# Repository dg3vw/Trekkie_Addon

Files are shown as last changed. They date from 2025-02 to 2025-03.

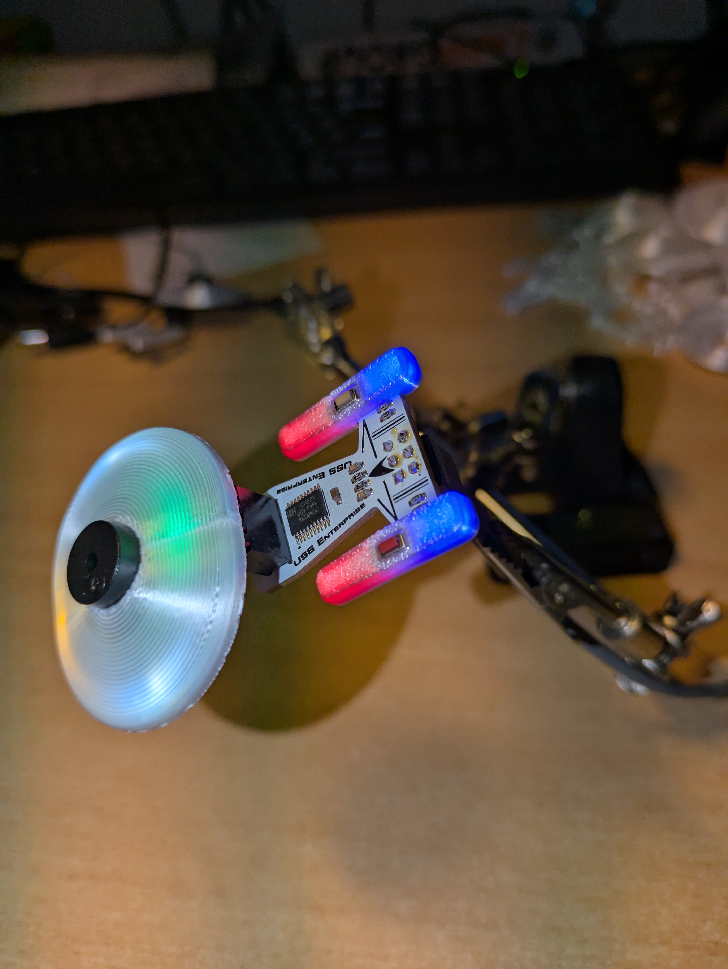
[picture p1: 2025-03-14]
pics/PXL_20250314_204137492.jpg

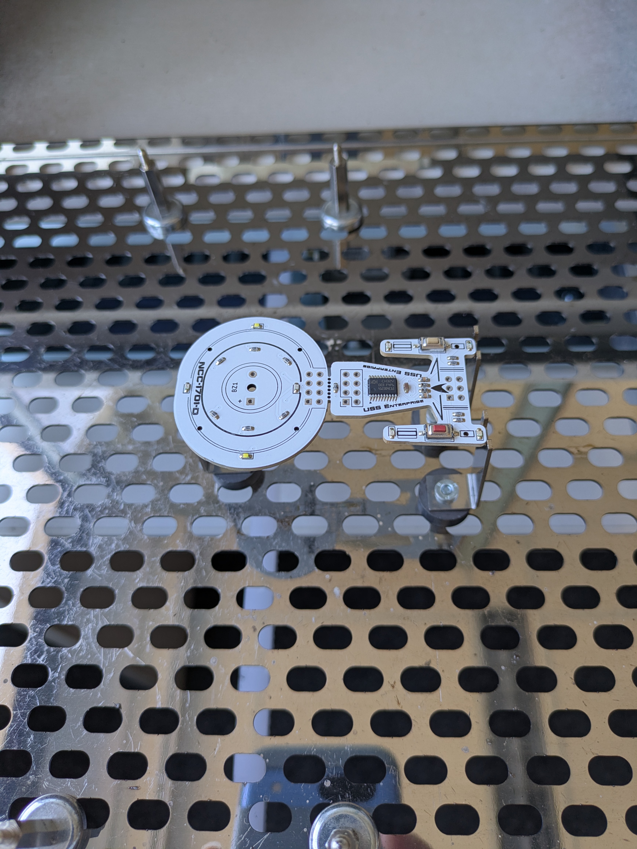
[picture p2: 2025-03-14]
pics/PXL_20250307_114811036.jpg

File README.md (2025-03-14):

# Trekkie_Addon - USS Enterprise SAO

my contribution to Hackaday Europe 2025 Badge SAO

## NCC-1701-D - USS Enterprise 
PXL_20250314_204249380 MP~2

### general 
* hardware compatible to 2024 Supercon 8 I2C prototyping petal SAO, using CH32v003 (see: https://github.com/Hack-a-Day/2024-Supercon-8-Add-On-Badge/tree/main/hardware/sao/i2c_proto_petal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)
* I added a few leds, two switches and a buzzer. Every LED is connected to a single gpio pin.
* you can change the light and sound as you wish, also with the PIpico on the badge

if u use my firmware, dont fire to much ;-)

### PINOUT: 
* PC0 - buzzer
* PC3 - front dish top led
* PC4 - engine nacelles left back
* PC5 - engine nacelles back
* PC6 - engine nacelles front
* PC7 - engine nacelles front
* PD0 - deflecor led
* PD1 - programming pin. connected to SAO connector pin 2
* PD2 - dish top left
* PD3 - dish top right
* PD4 - dish bottom left
* PD5 - dish bottom right
* PD6 - SWITCH 2 - fire the plasma cannon
* PD7 - SWITCH 1 - power up or reset (NRST), that can be changed to regular gpio using minichlink -D (from ch32fun)

## some impressions from the making:





PXL_20250314_204246564 MP

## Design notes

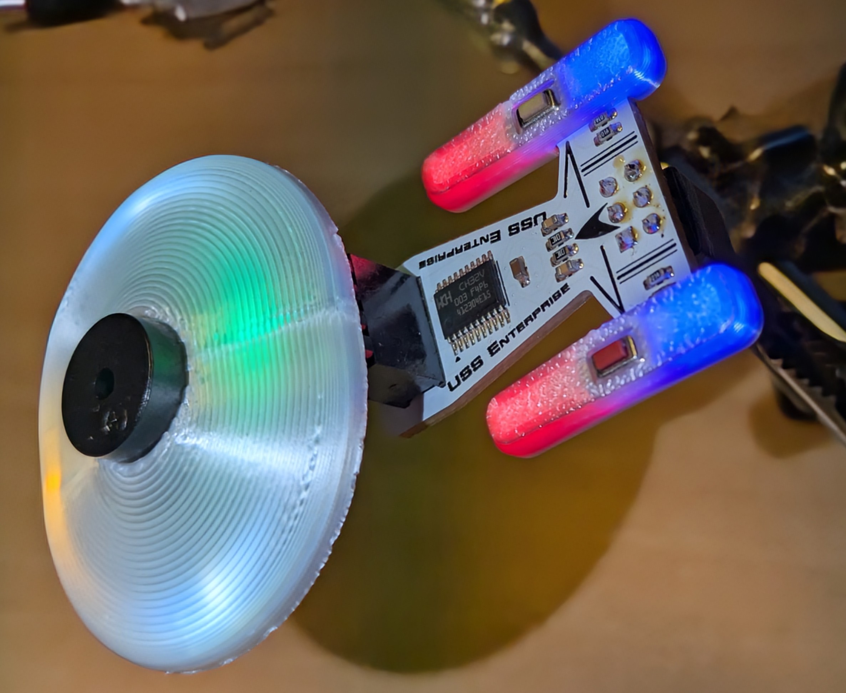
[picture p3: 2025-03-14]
pics/PXL_20250314_204137492~2.jpg

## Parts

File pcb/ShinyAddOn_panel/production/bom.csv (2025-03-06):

Designator | Footprint | Quantity | Value | LCSC Part #
BZ1_10, BZ1_9, BZ1_8, BZ1_7, BZ1_6, BZ1_5, BZ1_4, BZ1_3, BZ1_2, BZ1 | Buzzer_12x9.5RM7.6 | 10 | Buzzer
C1_10, C1_9, C1_8, C1_7, C1_6, C1_5, C1_4, C1_3, C1_2, C1, C2_10, C2_9, C2_8, C2_7, C2_6, C2_5, C2_4, C2_3, C2_2, C2 | 0603 | 20 | 1nF
C3_10, C3_9, C3_8, C3_7, C3_6, C3_5, C3_4, C3_3, C3_2, C3 | 0603 | 10 | 100nF
D1_10, D1_9, D1_8, D1_7, D1_6, D1_5, D1_4, D1_3, D1_2, D1 | 0603 | 10 | blue front powerled
D10_10, D10_9, D10_8, D10_7, D10_6, D10_5, D10_4, D10_3, D10_2, D10 | 0603 | 10 | LED dish bottom left
D11_10, D11_9, D11_8, D11_7, D11_6, D11_5, D11_4, D11_3, D11_2, D11 | 0603 | 10 | LED dish bottom right
D2_10, D2_9, D2_8, D2_7, D2_6, D2_5, D2_4, D2_3, D2_2, D2 | 0603 | 10 | lower front LED
D3_10, D3_9, D3_8, D3_7, D3_6, D3_5, D3_4, D3_3, D3_2, D3 | 0603 | 10 | LED blue right
D4_10, D4_9, D4_8, D4_7, D4_6, D4_5, D4_4, D4_3, D4_2, D4 | 0603 | 10 | LED blue left
D5_10, D5_9, D5_8, D5_7, D5_6, D5_5, D5_4, D5_3, D5_2, D5 | 0603 | 10 | LED blue front
D6_10, D6_9, D6_8, D6_7, D6_6, D6_5, D6_4, D6_3, D6_2, D6 | 0603 | 10 | LED red left
D7_10, D7_9, D7_8, D7_7, D7_6, D7_5, D7_4, D7_3, D7_2, D7 | 0603 | 10 | LED red right
D8_10, D8_9, D8_8, D8_7, D8_6, D8_5, D8_4, D8_3, D8_2, D8 | 0603 | 10 | LED dish top left
D9_10, D9_9, D9_8, D9_7, D9_6, D9_5, D9_4, D9_3, D9_2, D9 | 0603 | 10 | LED dish top right
J1_10, J1_9, J1_8, J1_7, J1_6, J1_5, J1_4, J1_3, J1_2, J1 | PinHeader_2x04_P2.54mm_Vertical | 10 | Conn_02x04_Odd_Even
J3_10, J3_9, J3_8, J3_7, J3_6, J3_5, J3_4, J3_3, J3_2, J3 | SolderJumper-2_P1.3mm_Open_RoundedPad1.0x1.5mm | 10 | GPIO
J4_10, J4_9, J4_8, J4_7, J4_6, J4_5, J4_4, J4_3, J4_2, J4 | PinSocket_2x04_P2.54mm_Vertical | 10 | saucer connetion
J5_10, J5_9, J5_8, J5_7, J5_6, J5_5, J5_4, J5_3, J5_2, J5 | PinHeader_2x03_P2.54mm_Vertical | 10 | SAO Connector
JP1_10, JP1_9, JP1_8, JP1_7, JP1_6, JP1_5, JP1_4, JP1_3, JP1_2, JP1 | SolderJumper-2_P1.3mm_Bridged_RoundedPad1.0x1.5mm | 10 | Jumper_2_Bridged
KIKIT_FID_B_1, KIKIT_FID_B_2, KIKIT_FID_B_3, KIKIT_FID_B_4, KIKIT_FID_T_1, KIKIT_FID_T_2, KIKIT_FID_T_3, KIKIT_FID_T_4 | Fiducial | 8 | Fiducial
KIKIT_MB_10_1, KIKIT_MB_10_2, KIKIT_MB_10_3, KIKIT_MB_10_4, KIKIT_MB_11_1, KIKIT_MB_11_2, KIKIT_MB_11_3, KIKIT_MB_11_4, KIKIT_MB_12_1, KIKIT_MB_12_2, KIKIT_MB_12_3, KIKIT_MB_12_4, KIKIT_MB_13_1, KIKIT_MB_13_2, KIKIT_MB_13_3, KIKIT_MB_13_4, KIKIT_MB_14_1, KIKIT_MB_14_2, KIKIT_MB_14_3, KIKIT_MB_14_4, KIKIT_MB_15_1, KIKIT_MB_15_2, KIKIT_MB_15_3, KIKIT_MB_15_4, KIKIT_MB_16_1, KIKIT_MB_16_2, KIKIT_MB_16_3, KIKIT_MB_16_4, KIKIT_MB_17_1, KIKIT_MB_17_2, KIKIT_MB_17_3, KIKIT_MB_17_4, KIKIT_MB_18_1, KIKIT_MB_18_2, KIKIT_MB_18_3, KIKIT_MB_18_4, KIKIT_MB_19_1, KIKIT_MB_19_2, KIKIT_MB_19_3, KIKIT_MB_19_4, KIKIT_MB_1_1, KIKIT_MB_1_2, KIKIT_MB_1_3, KIKIT_MB_1_4, KIKIT_MB_20_1, KIKIT_MB_20_2, KIKIT_MB_20_3, KIKIT_MB_20_4, KIKIT_MB_21_1, KIKIT_MB_21_2, KIKIT_MB_21_3, KIKIT_MB_21_4, KIKIT_MB_22_1, KIKIT_MB_22_2, KIKIT_MB_22_3, KIKIT_MB_22_4, KIKIT_MB_23_1, KIKIT_MB_23_2, KIKIT_MB_23_3, KIKIT_MB_23_4, KIKIT_MB_24_1, KIKIT_MB_24_2, KIKIT_MB_24_3, KIKIT_MB_24_4, KIKIT_MB_25_1, KIKIT_MB_25_2, KIKIT_MB_25_3, KIKIT_MB_25_4, KIKIT_MB_26_1, KIKIT_MB_26_2, KIKIT_MB_26_3, KIKIT_MB_26_4, KIKIT_MB_27_1, KIKIT_MB_27_2, KIKIT_MB_27_3, KIKIT_MB_27_4, KIKIT_MB_28_1, KIKIT_MB_28_2, KIKIT_MB_28_3, KIKIT_MB_28_4, KIKIT_MB_29_1, KIKIT_MB_29_2, KIKIT_MB_29_3, KIKIT_MB_29_4, KIKIT_MB_2_1, KIKIT_MB_2_2, KIKIT_MB_2_3, KIKIT_MB_2_4, KIKIT_MB_30_1, KIKIT_MB_30_2, KIKIT_MB_30_3, KIKIT_MB_30_4, KIKIT_MB_31_1, KIKIT_MB_31_2, KIKIT_MB_31_3, KIKIT_MB_31_4, KIKIT_MB_32_1, KIKIT_MB_32_2, KIKIT_MB_32_3, KIKIT_MB_32_4, KIKIT_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 | NPTH | 200 | NPTH
KIKIT_MB_46_8, KIKIT_MB_46_9, KIKIT_MB_47_1, KIKIT_MB_47_10, KIKIT_MB_47_11, KIKIT_MB_47_2, KIKIT_MB_47_3, KIKIT_MB_47_4, KIKIT_MB_47_5, KIKIT_MB_47_6, KIKIT_MB_47_7, KIKIT_MB_47_8, KIKIT_MB_47_9, KIKIT_MB_48_1, KIKIT_MB_48_10, KIKIT_MB_48_11, KIKIT_MB_48_2, KIKIT_MB_48_3, KIKIT_MB_48_4, KIKIT_MB_48_5, KIKIT_MB_48_6, KIKIT_MB_48_7, KIKIT_MB_48_8, KIKIT_MB_48_9, KIKIT_MB_4_1, KIKIT_MB_4_2, KIKIT_MB_4_3, KIKIT_MB_4_4, KIKIT_MB_5_1, KIKIT_MB_5_2, KIKIT_MB_5_3, KIKIT_MB_5_4, KIKIT_MB_6_1, KIKIT_MB_6_2, KIKIT_MB_6_3, KIKIT_MB_6_4, KIKIT_MB_7_1, KIKIT_MB_7_2, KIKIT_MB_7_3, KIKIT_MB_7_4, KIKIT_MB_8_1, KIKIT_MB_8_2, KIKIT_MB_8_3, KIKIT_MB_8_4, KIKIT_MB_9_1, KIKIT_MB_9_2, KIKIT_MB_9_3, KIKIT_MB_9_4, KIKIT_TO_1, KIKIT_TO_2, KIKIT_TO_3, KIKIT_TO_4 | NPTH | 52 | NPTH
R1_10, R1_9, R1_8, R1_7, R1_6, R1_5, R1_4, R1_3, R1_2, R1, R10_10, R10_9, R10_8, R10_7, R10_6, R10_5, R10_4, R10_3, R10_2, R10, R11_10, R11_9, R11_8, R11_7, R11_6, R11_5, R11_4, R11_3, R11_2, R11, R12_10, R12_9, R12_8, R12_7, R12_6, R12_5, R12_4, R12_3, R12_2, R12, R13_10, R13_9, R13_8, R13_7, R13_6, R13_5, R13_4, R13_3, R13_2, R13, R2_10, R2_9, R2_8, R2_7, R2_6, R2_5, R2_4, R2_3, R2_2, R2, R3_10, R3_9, R3_8, R3_7, R3_6, R3_5, R3_4, R3_3, R3_2, R3, R4_10, R4_9, R4_8, R4_7, R4_6, R4_5, R4_4, R4_3, R4_2, R4, R5_10, R5_9, R5_8, R5_7, R5_6, R5_5, R5_4, R5_3, R5_2, R5, R6_10, R6_9, R6_8, R6_7, R6_6, R6_5, R6_4, R6_3, R6_2, R6, R7_10, R7_9, R7_8, R7_7, R7_6, R7_5, R7_4, R7_3, R7_2, R7 | 0603 | 110 | 330
R8_10, R8_9, R8_8, R8_7, R8_6, R8_5, R8_4, R8_3, R8_2, R8, R9_10, R9_9, R9_8, R9_7, R9_6, R9_5, R9_4, R9_3, R9_2, R9 | 0603 | 20 | 10k
SW1_10, SW1_9, SW1_8, SW1_7, SW1_6, SW1_5, SW1_4, SW1_3, SW1_2, SW1, SW2_10, SW2_9, SW2_8, SW2_7, SW2_6, SW2_5, SW2_4, SW2_3, SW2_2, SW2 | SW_Tactile_SPST_NO_Straight_CK_PTS636Sx25SMTRLFS | 20 | SW_Push
U1_10, U1_9, U1_8, U1_7, U1_6, U1_5, U1_4, U1_3, U1_2, U1 | TSSOP-20_4.4x6.5mm_P0.65mm | 10 | CH32V003FxPx

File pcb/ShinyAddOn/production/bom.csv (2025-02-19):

Designator | Footprint | Quantity | Value | LCSC Part #
BZ1 | Buzzer_12x9.5RM7.6 | 1 | Buzzer
C1, C2 | 0603 | 2 | 1nF
C3 | 0603 | 1 | 100nF
D1 | 0603 | 1 | blue front powerled
D10 | 0603 | 1 | LED dish bottom left
D11 | 0603 | 1 | LED dish bottom right
D2 | 0603 | 1 | lower front LED
D3 | 0603 | 1 | LED blue right
D4 | 0603 | 1 | LED blue left
D5 | 0603 | 1 | LED blue front
D6 | 0603 | 1 | LED red left
D7 | 0603 | 1 | LED red right
D8 | 0603 | 1 | LED dish top left
D9 | 0603 | 1 | LED dish top right
J1 | PinHeader_2x04_P2.54mm_Vertical | 1 | Conn_02x04_Odd_Even
J3 | SolderJumper-2_P1.3mm_Open_RoundedPad1.0x1.5mm | 1 | GPIO
J4 | PinSocket_2x04_P2.54mm_Vertical | 1 | saucer connetion
J5 | PinHeader_2x03_P2.54mm_Vertical | 1 | SAO Connector
JP1 | SolderJumper-2_P1.3mm_Bridged_RoundedPad1.0x1.5mm | 1 | Jumper_2_Bridged
R1, R10, R11, R12, R13, R2, R3, R4, R5, R6, R7 | 0603 | 11 | 330
R8, R9 | 0603 | 2 | 10k
SW1, SW2 | SW_Tactile_SPST_NO_Straight_CK_PTS636Sx25SMTRLFS | 2 | SW_Push
U1 | TSSOP-20_4.4x6.5mm_P0.65mm | 1 | CH32V003FxPx

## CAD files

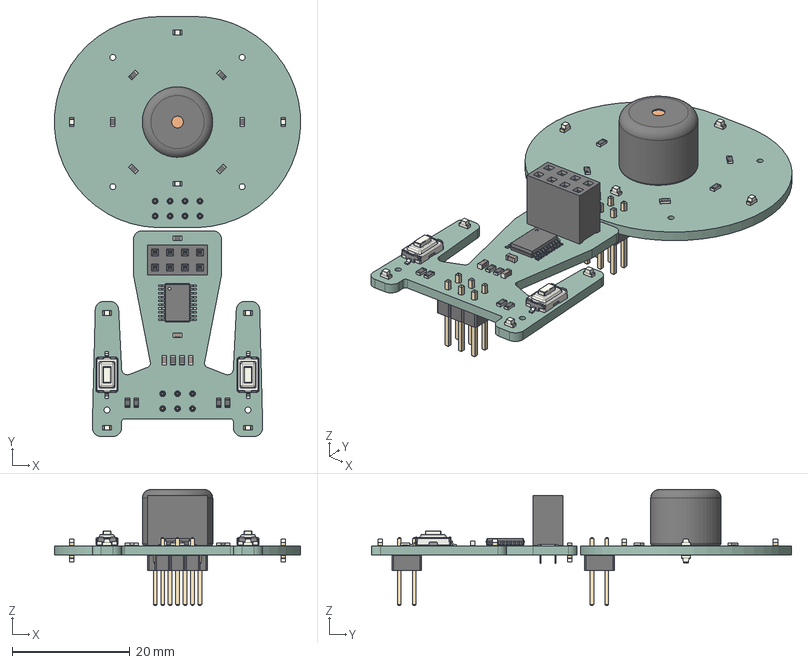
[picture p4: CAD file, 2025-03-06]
pcb/ShinyAddOn/ShinyAddOn.step
41.9 x 71.5 x 19.8 mm
SW_Tactile_SPST_NO_Straight_CK_PTS636Sx25SMTRLFS x 2
LED_0603_1608Metric x 11
C_0603_1608Metric x 3
R_0603_1608Metric x 13
TSSOP-20_4.4x6.5mm_P0.65mm
Buzzer_12x9.5RM7.6
PinSocket_2x04_P2.54mm_Vertical
PinHeader_2x04_P2.54mm_Vertical
PinHeader_2x03_P2.54mm_Vertical
ShinyAddOn_PCB_1
ShinyAddOn_PCB_2

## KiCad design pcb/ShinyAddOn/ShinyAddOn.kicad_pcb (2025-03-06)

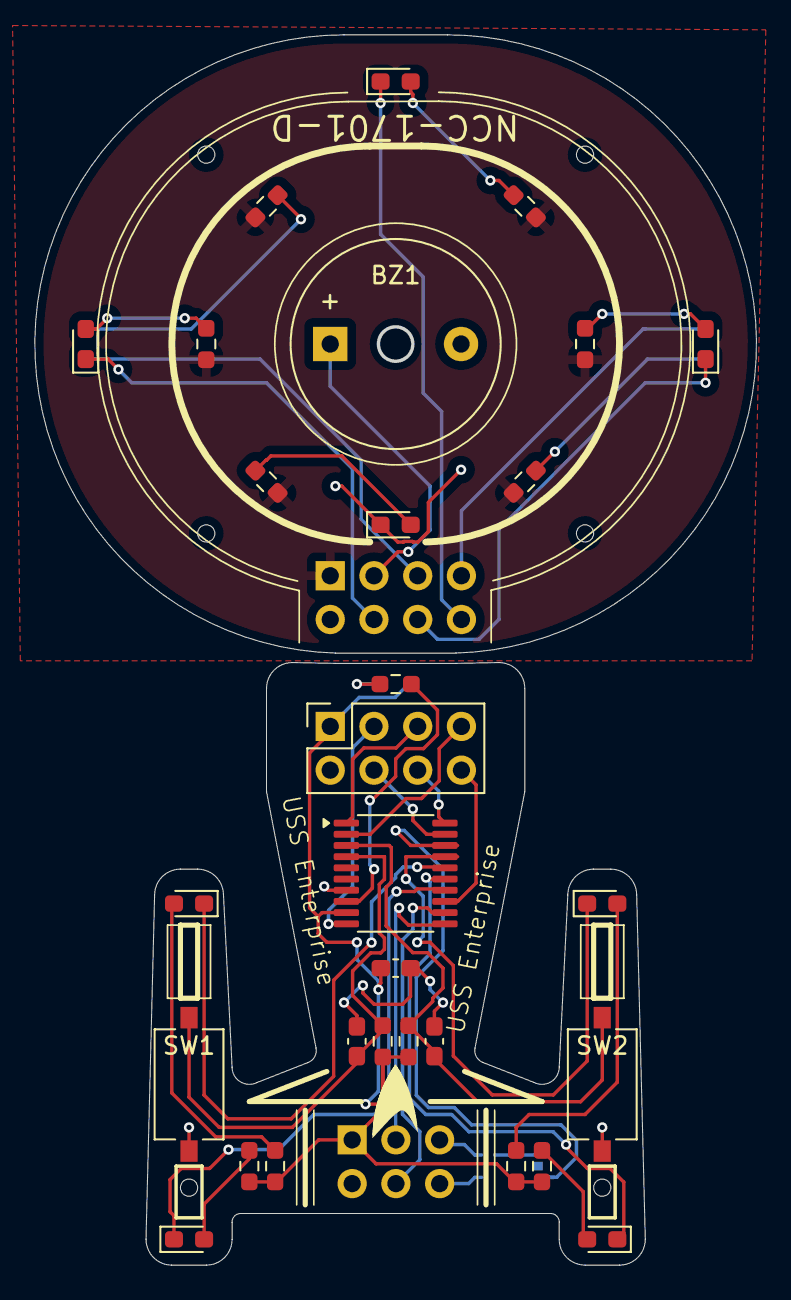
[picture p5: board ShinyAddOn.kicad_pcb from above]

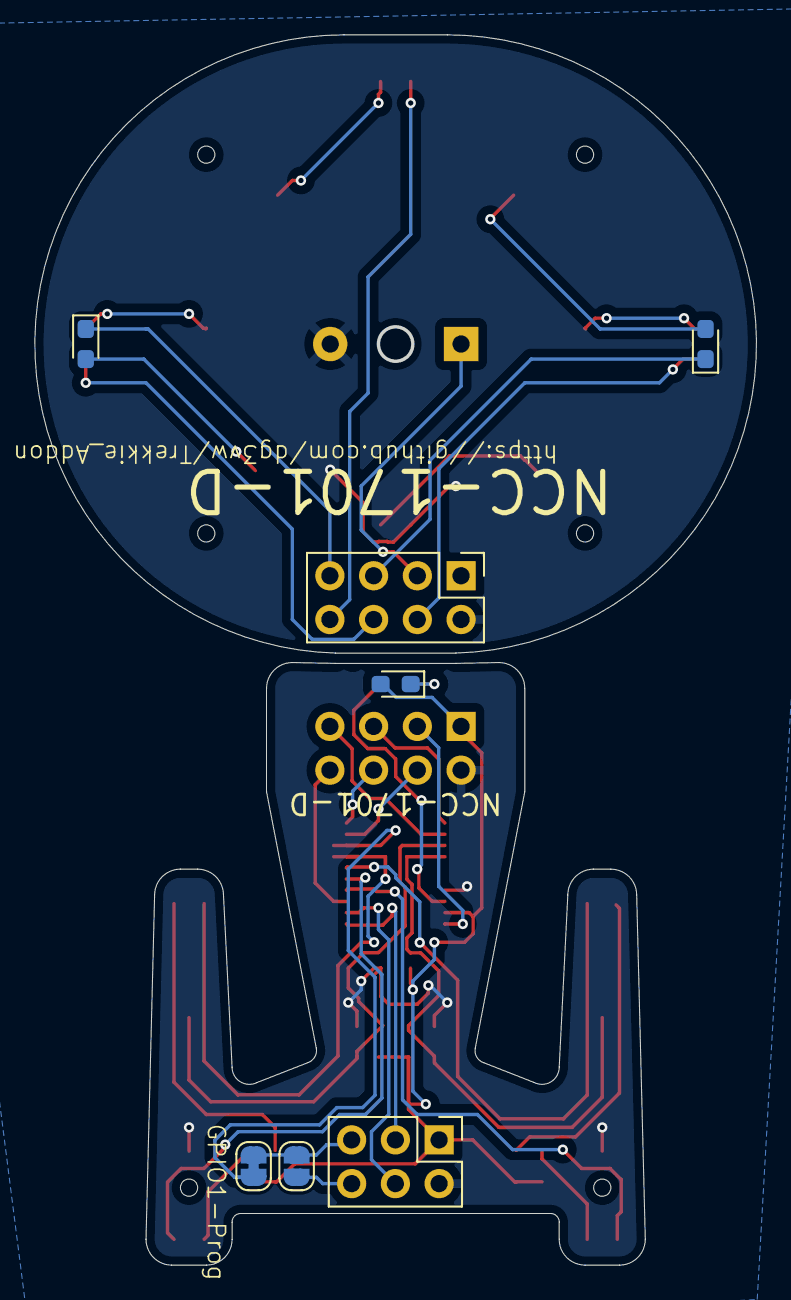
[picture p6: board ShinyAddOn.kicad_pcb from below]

Board: 2 copper layers, 41.9 x 71.5 mm, 36 parts (7 on the bottom side), 31 nets.

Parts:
BZ1: Buzzer; Buzzer_12x9.5RM7.6
C1, C2: 1nF; C_0603_1608Metric_Pad1.08x0.95mm_HandSolder
C3: 100nF; C_0603_1608Metric_Pad1.08x0.95mm_HandSolder
D1: blue front powerled; LED_0603_1608Metric_Pad1.05x0.95mm_HandSolder
D2: lower front LED; LED_0603_1608Metric_Pad1.05x0.95mm_HandSolder
D3: LED blue right; LED_0603_1608Metric_Pad1.05x0.95mm_HandSolder
D4: LED blue left; LED_0603_1608Metric_Pad1.05x0.95mm_HandSolder
D5: LED blue front; LED_0603_1608Metric_Pad1.05x0.95mm_HandSolder
D6: LED red left; LED_0603_1608Metric_Pad1.05x0.95mm_HandSolder
D7: LED red right; LED_0603_1608Metric_Pad1.05x0.95mm_HandSolder
D8: LED dish top left; LED_0603_1608Metric_Pad1.05x0.95mm_HandSolder
D9: LED dish top right; LED_0603_1608Metric_Pad1.05x0.95mm_HandSolder
D10: LED dish bottom left; LED_0603_1608Metric_Pad1.05x0.95mm_HandSolder
D11: LED dish bottom right; LED_0603_1608Metric_Pad1.05x0.95mm_HandSolder
J1: Conn_02x04_Odd_Even; PinHeader_2x04_P2.54mm_Vertical
J3: GPIO; SolderJumper-2_P1.3mm_Open_RoundedPad1.0x1.5mm
J4: saucer connetion; PinSocket_2x04_P2.54mm_Vertical
J5: SAO Connector; PinHeader_2x03_P2.54mm_Vertical
JP1: Jumper_2_Bridged; SolderJumper-2_P1.3mm_Bridged_RoundedPad1.0x1.5mm
R1, R2, R3, R4, R5, R6, R7, R10, R11, R12, R13: 330; R_0603_1608Metric_Pad0.98x0.95mm_HandSolder
R8, R9: 10k; R_0603_1608Metric_Pad0.98x0.95mm_HandSolder
SW1, SW2: SW_Push; SW_Tactile_SPST_NO_Straight_CK_PTS636Sx25SMTRLFS
U1: CH32V003FxPx; TSSOP-20_4.4x6.5mm_P0.65mm

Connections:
/GPIO1: J3.2, J5.5, JP1.1 (A)
/GPIO2: J3.1, J5.6
/LED dish bottom l: D10.1 (K), J1.5, J4.5, U1.1 (PD4)
/LED dish bottom r: D11.1 (K), J1.7, J4.7, U1.2 (PD5)
/LED dish top left: D8.1 (K), J1.4, J4.4, U1.19 (PD2)
/LED dish top right: D9.1 (K), J1.6, J4.6, U1.20 (PD3)
/SCL: J5.4, U1.12 (SCL)
/SDA: J5.3, U1.11 (SDA)
/blue gondeln left: D4.1 (K), U1.14 (PC4)
/blue gondeln right: D3.1 (K), U1.15 (PC5)
/blue_front: D5.1 (K), J1.8, J4.8, U1.13 (PC3)
/buzzer: BZ1.1 (+), J1.3, J4.3, U1.10 (PC0)
/red_gondeln_left: D6.1 (K), U1.16 (PC6)
/red_gondeln_right: D7.1 (K), U1.17 (PC7)
/sw1: C1.1, R9.2, SW1.1, U1.4 (PD7)
/sw2: C2.1, R8.2, SW2.1, U1.3 (PD6)
GND: BZ1.2 (-), C1.2, C2.2, C3.2, D1.1 (K), J1.2, J4.2, J5.2, SW1.2, SW2.2, U1.7 (VSS)
unnamed: D1.2 (A), R1.2
unnamed: D2.1 (K), R2.1
unnamed: D3.2 (A), R3.2
unnamed: D4.2 (A), R4.2
unnamed: D5.2 (A), R5.2
unnamed: D6.2 (A), R6.2
unnamed: D7.2 (A), R7.2
unnamed: D8.2 (A), R10.2
unnamed: D9.2 (A), R11.2
unnamed: D10.2 (A), R12.2
unnamed: D11.2 (A), R13.2
unnamed: JP1.2 (B), U1.18 (SWIO)
unnamed: R2.2, U1.8 (PD0)
VCC: C3.1, D2.2 (A), J1.1, J4.1, J5.1, R1.1, R3.1, R4.1, R5.1, R6.1, R7.1, R8.1, R9.1, R10.1, R11.1, R12.1, R13.1, U1.9 (VDD)

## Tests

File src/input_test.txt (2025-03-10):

#include <Arduino.h>
#define LED_DISH_BOTTOM_LEFT PD4
#define LED_DISH_BOTTOM_RIGHT PD5

// Function to configure PD7 as an input pin
void configurePD7AsInput() {
  // Enable the clock for GPIO port D
  RCC_APB2PeriphClockCmd(RCC_APB2Periph_GPIOD, ENABLE);

  // Configure PD7 as an input with pull-up resistor
  GPIO_InitTypeDef GPIO_InitStructure;
  GPIO_InitStructure.GPIO_Pin = GPIO_Pin_7;
  GPIO_InitStructure.GPIO_Mode = GPIO_Mode_IPU; // Use GPIO_Mode_IPU for internal pull-up
  GPIO_Init(GPIOD, &GPIO_InitStructure);
}

void setup() {
  // Configure PD7 as input
  configurePD7AsInput();
  pinMode(LED_DISH_BOTTOM_LEFT, OUTPUT);
  pinMode(LED_DISH_BOTTOM_RIGHT, OUTPUT);

  digitalWrite(LED_DISH_BOTTOM_RIGHT, LOW); 

}

void loop() {
  // Read the state of PD7
  int pd7State = digitalRead(PD7);

  // Print the state to the serial monitor
  if (pd7State == HIGH) {
    digitalWrite(LED_DISH_BOTTOM_LEFT, HIGH);
  } else {
    digitalWrite(LED_DISH_BOTTOM_LEFT, LOW);
  }

  // Delay for 1 second
  delay(1000);
}

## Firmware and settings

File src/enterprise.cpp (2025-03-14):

#include <NonBlockingRtttl.h>
#include <Arduino.h>

// Define LED pins
#define LED_FRONT PC3
#define BUZZER PC0
#define LED_BLUE_MOTOR_LEFT PC4
#define LED_BLUE_MOTOR_RIGHT PC5
#define LED_RED_MOTOR_LEFT PC6
#define LED_RED_MOTOR_RIGHT PC7
#define LED_DISH_TOP_LEFT PD2
#define LED_DISH_TOP_RIGHT PD3
#define LED_DISH_BOTTOM_LEFT PD4
#define LED_DISH_BOTTOM_RIGHT PD5
#define LED_DEFLECTOR PD0
#define SWITCH_1 PD6
#define SWITCH_2 PD7 // <- work only if Pin D7 is reprogrammed to be an input (not NRST)

// Structure to hold LED timing parameters
struct LedTiming {
    unsigned long previousMillis;
    int ledState;
    const long (*intervalData)[3]; // Pointer to an array of arrays [on, off, repeat]
    const int numIntervals;        // Number of intervals in the array
    const int ledPin;
    int timingIndex;         // Index to switch between the timing sets
    int currentRepeat; // Counter for the current repeat of the interval
};

// Define interval arrays for each LED (example)
// Top Dish LEDs
const long topDishLeftData[][3] = {
    {2000, 15, 1},   // 100ms ON, 900ms OFF, repeat 3 times
    
};

const long topDishRightData[][3] = {
    {2100, 15, 1},   // 100ms ON, 900ms OFF, repeat 3 times
};

// Bottom Dish LEDs
const long bottomDishLeftData[][3] = {
    {50, 50, 4},    // 500ms ON, 100ms OFF, repeat 1 time
    {50, 200, 1},   // 200ms ON, 500ms OFF, repeat 2 time
    {2000, 350, 1},   // 200ms ON, 500ms OFF, repeat 2 time
};

const long bottomDishRightData[][3] = {
    {50, 50, 4},    // 500ms ON, 100ms OFF, repeat 1 time
    {50, 200, 1},   // 200ms ON, 500ms OFF, repeat 2 time
    {2000, 350, 1},   // 200ms ON, 500ms OFF, repeat 2 time
};

// Front LED
const long frontLedData[][3] = {
    {2500, 500, 1},   // 5000ms ON, 60ms OFF, repeat 1 time
};

// Blue Motor LEDs
const long blueMotorLeftData[][3] = {
    {100, 50, 1},
    {50, 200, 1},   
    {6000, 2000, 1},   
};

const long blueMotorRightData[][3] = {
    {100, 50, 1},
    {50, 200, 1},   
    {6000, 2000, 1},
};

// Red Motor LEDs
const long redMotorLeftData[][3] = {
    {5000, 500, 1},   // 5000ms ON, 60ms OFF, repeat 1 time
};

const long redMotorRightData[][3] = {
    {5000, 500, 1},   // 5000ms ON, 60ms OFF, repeat 1 time
};

// Deflector LED
const long deflectorLedData[][3] = {
    {3000, 700, 1},   // 5000ms ON, 60ms OFF, repeat 1 time
};

// Define LED timing parameters and instances
LedTiming topDishLeds[] = {
    {0, LOW, topDishLeftData, sizeof(topDishLeftData) / sizeof(topDishLeftData[0]), LED_DISH_TOP_LEFT, 0, 0},
    {0, LOW, topDishRightData, sizeof(topDishRightData) / sizeof(topDishRightData[0]), LED_DISH_TOP_RIGHT, 0, 0}};

LedTiming bottomDishLeds[] = {
    {0, LOW, bottomDishLeftData, sizeof(bottomDishLeftData) / sizeof(bottomDishLeftData[0]), LED_DISH_BOTTOM_LEFT, 0, 0},
    {0, LOW, bottomDishRightData, sizeof(bottomDishRightData) / sizeof(bottomDishRightData[0]), LED_DISH_BOTTOM_RIGHT, 0, 0}};

LedTiming frontLed = {0, LOW, frontLedData, sizeof(frontLedData) / sizeof(frontLedData[0]), LED_FRONT, 0, 0};

LedTiming blueMotorLeds[] = {
    {0, LOW, blueMotorLeftData, sizeof(blueMotorLeftData) / sizeof(blueMotorLeftData[0]), LED_BLUE_MOTOR_LEFT, 0, 0},
    {0, LOW, blueMotorRightData, sizeof(blueMotorRightData) / sizeof(blueMotorRightData[0]), LED_BLUE_MOTOR_RIGHT, 0, 0}};

LedTiming redMotorLeds[] = {
    {0, LOW, redMotorLeftData, sizeof(redMotorLeftData) / sizeof(redMotorLeftData[0]), LED_RED_MOTOR_LEFT, 0, 0},
    {0, LOW, redMotorRightData, sizeof(redMotorRightData) / sizeof(redMotorRightData[0]), LED_RED_MOTOR_RIGHT, 0, 0}};

LedTiming deflectorLed = {0, LOW, deflectorLedData, sizeof(deflectorLedData) / sizeof(deflectorLedData[0]), LED_DEFLECTOR, 0, 0};

static bool switch1Pressed = false; // Flag to track switch 1 press state
static bool switch2Pressed = false; // Flag to track switch 2 press state
unsigned long currentMillis = millis();

int leds[] = {
    LED_FRONT, LED_BLUE_MOTOR_LEFT, LED_BLUE_MOTOR_RIGHT,
    LED_RED_MOTOR_LEFT, LED_RED_MOTOR_RIGHT, LED_DISH_TOP_LEFT,
    LED_DISH_TOP_RIGHT, LED_DISH_BOTTOM_LEFT, LED_DISH_BOTTOM_RIGHT,
    LED_DEFLECTOR};

const char *startrek = "StarTrekTNG:d=32,o=6,b=63:8f#.5,b.5,d#.,8c#.,a.5,g#.,4f#.,a.5,e.,f#.,g#.,e.,8d#,8c#,8b.5,d#.,b.5,2c#";
const char *rickroll = "RickRoll:d=4,o=5,b=200:8g,8a,8c6,8a,e6,8p,e6,8p,d6.,p,8p,8g,8a,8c6,8a,d6,8p,d6,8p,c6,8b,a.,8g,8a,8c6,8a,2c6,d6,b,a,g.,8p,g,2d6,2c6.,p,8g,8a,8c6,8a,e6,8p,e6,8p,d6.,p,8p,8g,8a,8c6,8a,2g6,b,c6.,8b,a,8g,8a,8c6,8a,2c6,d6,b,a,g.,8p,g,2d6,2c6.";


// Zapping sound parameters (for SWITCH_1)
const int zapFrequencies[] = {400, 600, 800, 1000, 800, 600, 400, 300, 200}; // Frequencies for the zap sound
const long zapDurations[] = {20, 20, 20, 20, 20, 20, 20, 30, 50};   // Durations for each frequency (milliseconds)
const int numZapTones = sizeof(zapFrequencies) / sizeof(zapFrequencies[0]);
unsigned long zapStartTime = 0; // Stores the start time of the zap sound
int zapToneIndex = 0;          // Index of the current tone
bool isZapping = false;        // Flag to indicate if the zapping sound is playing

// New sound parameters (for SWITCH_2)
const int beepFrequencies[] = {800, 1200, 1600, 2000}; // Frequencies for the beep sound
const long beepDurations[] = {50, 50, 50, 100};        // Durations for each frequency (milliseconds)
const int numBeepTones = sizeof(beepFrequencies) / sizeof(beepFrequencies[0]);
unsigned long beepStartTime = 0; // Stores the start time of the beep sound
int beepToneIndex = 0;          // Index of the current tone
bool isBeeping = false;        // Flag to indicate if the beep sound is playing

// New variables for rickroll functionality
int switch1PressCount = 0; // Counter for switch 1 presses
bool isRickrolling = false;  // Flag to indicate if Rickroll is playing
unsigned long rickrollBlinkMillis = 0;
int rickrollBlinkState = LOW;


// Function to play Rickroll
void playRickroll() {
    if (!isRickrolling) {
        isRickrolling = true;
        rtttl::begin(BUZZER, rickroll);
    }
    if (rtttl::done()) {
        isRickrolling = false;
        //reset leds
        for (int i = 0; i < sizeof(leds) / sizeof(leds[0]); i++) {
            digitalWrite(leds[i], HIGH); 
        }
    } else {
        rtttl::play();
    }
}

void setup() {
    pinMode(LED_FRONT, OUTPUT);
    pinMode(BUZZER, OUTPUT);
    pinMode(LED_BLUE_MOTOR_LEFT, OUTPUT);
    pinMode(LED_BLUE_MOTOR_RIGHT, OUTPUT);
    pinMode(LED_RED_MOTOR_LEFT, OUTPUT);
    pinMode(LED_RED_MOTOR_RIGHT, OUTPUT);
    pinMode(LED_DISH_TOP_LEFT, OUTPUT);
    pinMode(LED_DISH_TOP_RIGHT, OUTPUT);
    pinMode(LED_DISH_BOTTOM_LEFT, OUTPUT);
    pinMode(LED_DISH_BOTTOM_RIGHT, OUTPUT);
    pinMode(LED_DEFLECTOR, OUTPUT);
    pinMode(SWITCH_1, INPUT_PULLUP); // Use internal pull-up resistor
    pinMode(SWITCH_2, INPUT_PULLUP); // Use internal pull-up resistor

    for (int i = 0; i < sizeof(leds) / sizeof(leds[0]); i++) {
        digitalWrite(leds[i], HIGH); // Start all LEDs as off
    }

    rtttl::begin(BUZZER, startrek);
    while (!rtttl::done()) {
        rtttl::play();
    }
}

void handleLedBlinking(LedTiming &led) {
    unsigned long currentMillis = millis();
    long intervalOn = led.intervalData[led.timingIndex][0];
    long intervalOff = led.intervalData[led.timingIndex][1];
    int intervalRepeat = led.intervalData[led.timingIndex][2];

    if (led.ledState == LOW && currentMillis - led.previousMillis >= intervalOn) {
        led.previousMillis = currentMillis;
        led.ledState = HIGH;
        digitalWrite(led.ledPin, led.ledState);
    } else if (led.ledState == HIGH && currentMillis - led.previousMillis >= intervalOff) {
        led.previousMillis = currentMillis;
        led.ledState = LOW;
        digitalWrite(led.ledPin, led.ledState);
        led.currentRepeat++;

        if (led.currentRepeat >= intervalRepeat) {
            led.timingIndex = (led.timingIndex + 1) % led.numIntervals;
            led.currentRepeat = 0; // Reset the repeat counter
        }
    }
}


void handleLedGroupBlinking(LedTiming leds[], int count) {
    for (int i = 0; i < count; i++) {
        handleLedBlinking(leds[i]);
    }
}

// Function to play the zapping sound
void playZapSound() {
    if (isZapping) {
        unsigned long currentMillis = millis();
        if (currentMillis - zapStartTime >= zapDurations[zapToneIndex]) {
            zapToneIndex++;
            zapStartTime = currentMillis;
            if (zapToneIndex >= numZapTones) {
                isZapping = false;
                noTone(BUZZER);
            } else {
                tone(BUZZER, zapFrequencies[zapToneIndex]);
            }
        }
    }
}
// Function to play the new beep sound (for SWITCH_2)
void playBeepSound() {
    if (isBeeping) {
        unsigned long currentMillis = millis();
        if (currentMillis - beepStartTime >= beepDurations[beepToneIndex]) {
            beepToneIndex++;
            beepStartTime = currentMillis;
            if (beepToneIndex >= numBeepTones) {
                isBeeping = false;
                noTone(BUZZER);
            } else {
                tone(BUZZER, beepFrequencies[beepToneIndex]);
            }
        }
    }
}

void rickrollBlink() {
    unsigned long currentMillis = millis();
    if (currentMillis - rickrollBlinkMillis >= 50) {
        rickrollBlinkMillis = currentMillis;
        rickrollBlinkState = !rickrollBlinkState; // Toggle state
        if (rickrollBlinkState == HIGH) {
            int randomIndex = random(sizeof(leds) / sizeof(leds[0]));
            digitalWrite(leds[randomIndex], LOW);
        } else {
            for (int i = 0; i < sizeof(leds) / sizeof(leds[0]); i++) {
                digitalWrite(leds[i], HIGH);
            }
        }
    }
}

void loop() {
    unsigned long currentMillis = millis(); // Moved inside the loop!

    if (!isRickrolling) {
        // Handle top dish LEDs blinking
        handleLedGroupBlinking(topDishLeds, sizeof(topDishLeds) / sizeof(topDishLeds[0]));

        // Handle bottom dish LEDs blinking
        handleLedGroupBlinking(bottomDishLeds, sizeof(bottomDishLeds) / sizeof(bottomDishLeds[0]));

        // Handle Front LED blinking
        handleLedBlinking(frontLed);

        // Handle blue motor LEDs blinking
        handleLedGroupBlinking(blueMotorLeds, sizeof(blueMotorLeds) / sizeof(blueMotorLeds[0]));

        // Handle red motor LEDs blinking
        handleLedGroupBlinking(redMotorLeds, sizeof(redMotorLeds) / sizeof(redMotorLeds[0]));
    }

    // Handle deflector LED blinking when switch 1 is pressed and play sound
    if (digitalRead(SWITCH_1) == LOW) { // Switch is active LOW
        if (!switch1Pressed) {
            switch1PressCount++;
            switch1Pressed = true;
            if (!isZapping) {
                isZapping = true;
                zapToneIndex = 0;
                zapStartTime = currentMillis;
                tone(BUZZER, zapFrequencies[zapToneIndex]);
            }
        }
    } else {
        switch1Pressed = false;
        if (switch1PressCount >= 10 && !isRickrolling) {
            switch1PressCount = 0;
            playRickroll();
        }
    }

    if(isRickrolling){
        rickrollBlink();
        playRickroll();
    }

    // Handle new beep sound when switch 2 is pressed <- work only if Pin D7 is reprogrammed to be an input (not NRST)
    if (digitalRead(SWITCH_2) == LOW) { // Switch is active LOW
        switch2Pressed = true;
        if (!isBeeping) {
            isBeeping = true;
            beepToneIndex = 0;
            beepStartTime = currentMillis;
            tone(BUZZER, beepFrequencies[beepToneIndex]);
        }
    } else {
        switch2Pressed = false;
    }

    if (switch1Pressed && !isRickrolling) {
                handleLedBlinking(deflectorLed);
             } else if(!isRickrolling) {
                 digitalWrite(LED_DEFLECTOR, HIGH); // Keep deflector off when switch is not pressed
             }
             
             if (!isRickrolling) {
                 playZapSound(); // Play the zapping sound if it's active
             } 
             playBeepSound(); // Play the beep sound if it's active
        
        }

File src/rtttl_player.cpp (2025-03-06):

#include <NonBlockingRtttl.h>

//project's contants
#define BUZZER_PIN PC0
#define BLUE_LED_PIN PD0
const char * tetris = "tetris:d=4,o=5,b=160:e6,8b,8c6,8d6,16e6,16d6,8c6,8b,a,8a,8c6,e6,8d6,8c6,b,8b,8c6,d6,e6,c6,a,2a,8p,d6,8f6,a6,8g6,8f6,e6,8e6,8c6,e6,8d6,8c6,b,8b,8c6,d6,e6,c6,a,a";
const char * arkanoid = "Arkanoid:d=4,o=5,b=140:8g6,16p,16g.6,2a#6,32p,8a6,8g6,8f6,8a6,2g6";
const char * startrek = "Star Trek:o=5,d=16,b=63,b=63:8f.,a#,4d#6.,8d6,a#.,g.,c6.,4f6";
const char * startrekng = "StarTrekTNG:d=32,o=6,b=63:8f#.5,b.5,d#.,8c#.,a.5,g#.,4f#.,a.5,e.,f#.,g#.,e.,8d#,8c#,8b.5,d#.,b.5,2c#";
const char * mario = "mario:d=4,o=5,b=100:16e6,16e6,32p,8e6,16c6,8e6,8g6,8p,8g,8p,8c6,16p,8g,16p,8e,16p,8a,8b,16a#,8a,16g.,16e6,16g6,8a6,16f6,8g6,8e6,16c6,16d6,8b,16p,8c6,16p,8g,16p,8e,16p,8a,8b,16a#,8a,16g.,16e6,16g6,8a6,16f6,8g6,8e6,16c6,16d6,8b,8p,16g6,16f#6,16f6,16d#6,16p,16e6,16p,16g#,16a,16c6,16p,16a,16c6,16d6,8p,16g6,16f#6,16f6,16d#6,16p,16e6,16p,16c7,16p,16c7,16c7,p,16g6,16f#6,16f6,16d#6,16p,16e6,16p,16g#,16a,16c6,16p,16a,16c6,16d6,8p,16d#6,8p,16d6,8p,16c6";
const char * giveyouup = "GiveYouUp:d=4,o=5,b=200:8g,8a,8c6,8a,e6,8p,e6,8p,d.6,p,8p,8g,8a,8c6,8a,d6,8p,d6,8p,c6,8b,a.,8g,8a,8c6,8a,2c6,d6,b,a,g.,8p,g,2d6,2c.6,p,8g,8a,8c6,8a,e6,8p,e6,8p,d.6,p,8p,8g,8a,8c6,8a,2g6,b,c.6,8b,a,8g,8a,8c6,8a,2c6,d6,b,a,g.,8p,g,2d6,2c.6";
const char * pirates = "Piratesof:d=4,o=6,b=100:8a.5,8c.,8d.,8c,16a_5,8a5,16a5,8g5,16g5,f5,16p,16a5,16a.5,32p,16a5,16a5,16a5,16a5,16a5,16a5,16a5,16a5,16a5,16a5,16d.,32p,16a5,16f5,16f5,16g5,16a.5,p,16a5,16a_5,16a_5,16a_5,16g5,16g5,16g5,16a5,16a5,16a5,16f5,16f5,16f5,16g5,16g5,16g5,16g5,16a5";
const char * thegood = "Thegood,:d=4,o=6,b=63:32c,32f,32c,32f,c,8g_5,8a_5,f5,8p,32c,32f,32c,32f,c,8g_5,8a_5,d_";
const char * startrek1 = "we-rock:d=4,o=6,b=225:2b.4,4e.5,1a5,4g#.5,4e.5,4c#.5,4f#.5,2b.5,4b.5,2d#.6,";
const char * startrek2 = "StarTrek:d=4,o=5,b=80:8g,16c6,f6,16e6,16c6,16a,16d6,8g6,8p,8g,16c6,f6,16e6,16c6,16a,16d6,8g6";
const char * startrek3 = "Star Trek: d=4,o=5,b=63:8f.,16a#,d#.6,8d6,16a#.,16g.,16c.6,f6";
const char * startrek4 = "TheNextG:d=4,o=5,b=100:8f#6,16a#6,16a#6,16d#7,8c#7,16p,16g#6,16g#7,16g#7,8f#7,8p,16g#6,8f#7,16p,8d#7,16p,8d#7,16p,16d#7,16a#6,16d#7,8c#7";   
const char * startrek5 = "Communic:d=4,o=5,b=100:16g#7,8a#7,16a#7,16a#7,8f#7";

byte songIndex = 0; //which song to play when the previous one finishes

void setup() {
  pinMode(BUZZER_PIN, OUTPUT);
  pinMode(BLUE_LED_PIN, OUTPUT);

  Serial.begin(115200);
  Serial.println();
  
}

void loop() {
  if ( !rtttl::isPlaying() )
  {
    if (songIndex == 0)
    {
      rtttl::begin(BUZZER_PIN, startrek5);
      songIndex++; //ready for next song
      delay(5000);

      //play for 5 sec then stop.
      //note: this is a blocking code section
      //used to demonstrate the use of stop
      /*unsigned long start = millis();
      while( millis() - start < 5000 ) 
      {
        rtttl::play();
      }
      rtttl::stop();
      */
    }
    else if (songIndex == 1)
    {
      rtttl::begin(BUZZER_PIN, startrek2 );
      songIndex++; //ready for next song
      delay(5000); //play for 5 sec then stop.
    }
    else if (songIndex == 2)
    {
      rtttl::begin(BUZZER_PIN,startrekng);
      songIndex++; //ready for next song
    }
  }
  else
  {
    rtttl::play();
  }
}

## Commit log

2025-02-02 initial commit, pcb und platformio project data added
    [ShinyAddOn.kicad_pcb, ShinyAddOn.kicad_sch]
2025-02-16 worked on the pcb
    [ShinyAddOn.kicad_pcb, ShinyAddOn.kicad_sch]
2025-02-19 pcb updated
    [ShinyAddOn.kicad_pcb, ShinyAddOn.kicad_sch, ShinyAddOn_panel.kicad_pcb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]
2025-03-06 panel tests
    [ShinyAddOn.kicad_pcb, ShinyAddOn.step, bom.csv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]
